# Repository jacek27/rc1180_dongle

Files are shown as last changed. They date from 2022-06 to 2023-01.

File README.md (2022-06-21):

# rc1180_dongle

Used the library files from SnapEDA https://www.snapeda.com/

PCB for RadioCraft's RC1180-MBUS3 module with CH340C for usage with https://github.com/weetmuts/wmbusmeters

Trace for antena was calculated using https://www.pcbway.com/pcb_prototype/impedance_calculator.html


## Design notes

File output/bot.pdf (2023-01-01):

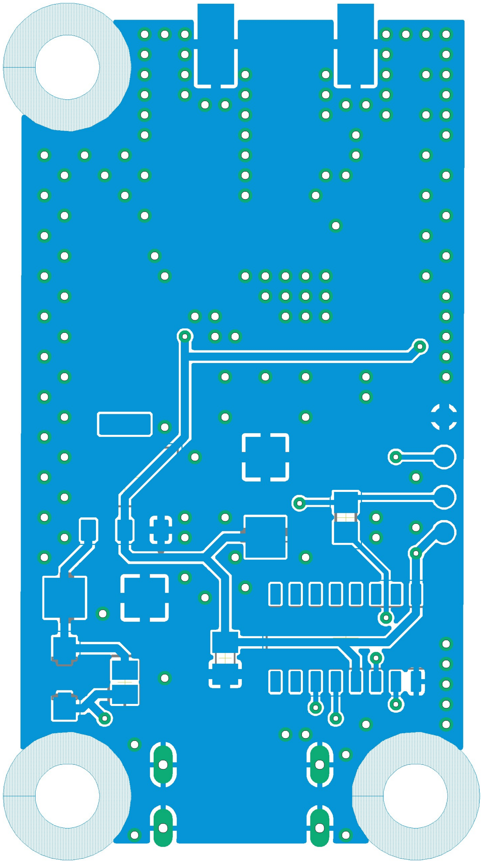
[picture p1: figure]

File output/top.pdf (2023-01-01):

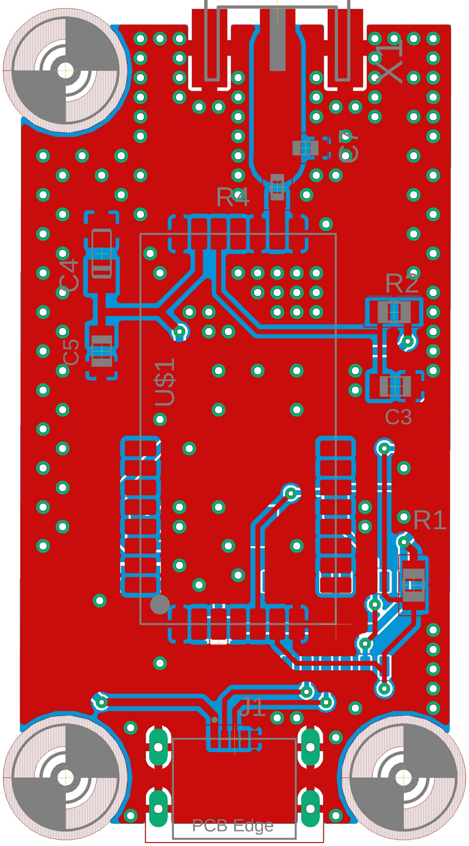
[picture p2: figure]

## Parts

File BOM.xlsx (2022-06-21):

Qty | Value | Device | Package | Parts | TME_PN | LINK | Description
3 | 100nF | C-EUC0805K | C0805K | C3, C5, C6 |  |  | CAPACITOR, European symbol
2 | 22uF | CPOL-EUC/6032-28R | C/6032-28R | C1, C2 | 293D226X9010C2TE3 | https://www.tme.eu/pl/details/293d226x9010c2te3/kondensatory-tantalowe-smd/vishay/ | POLARIZED CAPACITOR, European symbol
1 | 2u2F | CPOL-EUA/3216-18W | A/3216-18W | C4 | T491A225K020AT | https://www.tme.eu/pl/details/t491a225k020at/kondensatory-tantalowe-smd/kemet/ | POLARIZED CAPACITOR, European symbol
1 | 470R | R-EU_R0805 | R0805 | R3 |  |  | RESISTOR, European symbol
1 | 47642-0001 | 47642-0001 | MOLEX_47642-0001 | J1 | 476420001 | https://www.tme.eu/pl/details/mx-47642-0001/zlacza-usb-i-ieee1394/molex/476420001/ | Micro-USB B Receptacle, Mid-Mount, with Through Hole Solder Tab, Gold (Au) Flash Plating, without Mylar, Lead-Free
1 | 5k6 | R-EU_R0805 | R0805 | R2 |  |  | RESISTOR, European symbol
1 | 8k2 | R-EU_R0805 | R0805 | R1 |  |  | RESISTOR, European symbol
1 | AMS1117 | AMS1117 | SOT229P700X180-4N | U2 |  | https://elty.pl/pl/p/Stabilizator-napiecia-AMS1117-3%2C3V-SOT223-5-sztuk/972 | Sot223/Pkg 1-Amp 5-Volt Low Drop Out Voltage Regulatator
1 | CH340C | CH340C | SOIC127P600X180-16N | U1 |  | https://elty.pl/pl/p/Uklad-CH340C-SOP-16-konwerter-USB-TTL/2845 | USB to serial chip CH340
1 | MBR0540 | MBR0540 | SOD123 | U$2 | MBR0540-TP | https://www.tme.eu/pl/details/mbr0540-tp/diody-schottky-smd/micro-commercial-components/
1 | RC1180-MBUS3 | RC1180-MBUS3 | RC1180-MBUS3 | U$1 | RC1180-MBUS3 | https://www.tme.eu/pl/details/rc1180-mbus3/moduly-rf/radiocrafts/
1 | SMA-142-0701-801/806 | SMA-142-0701-801/806 | J502-ND-142-0701-801/806 | X1 | KAB-06318 | https://allegro.pl/oferta/zlacze-zenskie-sma-do-druku-proste-50ohm-12145586412 | SMA 50 Ohm End Launch Jack Receptacle - Round Contact
1 | TBD | C-EUC0603 | C0603 | C7 |  |  | CAPACITOR, European symbol
1 | TBD | R-EU_R0603 | R0603 | R4 |  |  | RESISTOR, European symbol

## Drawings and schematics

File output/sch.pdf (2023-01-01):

A

A

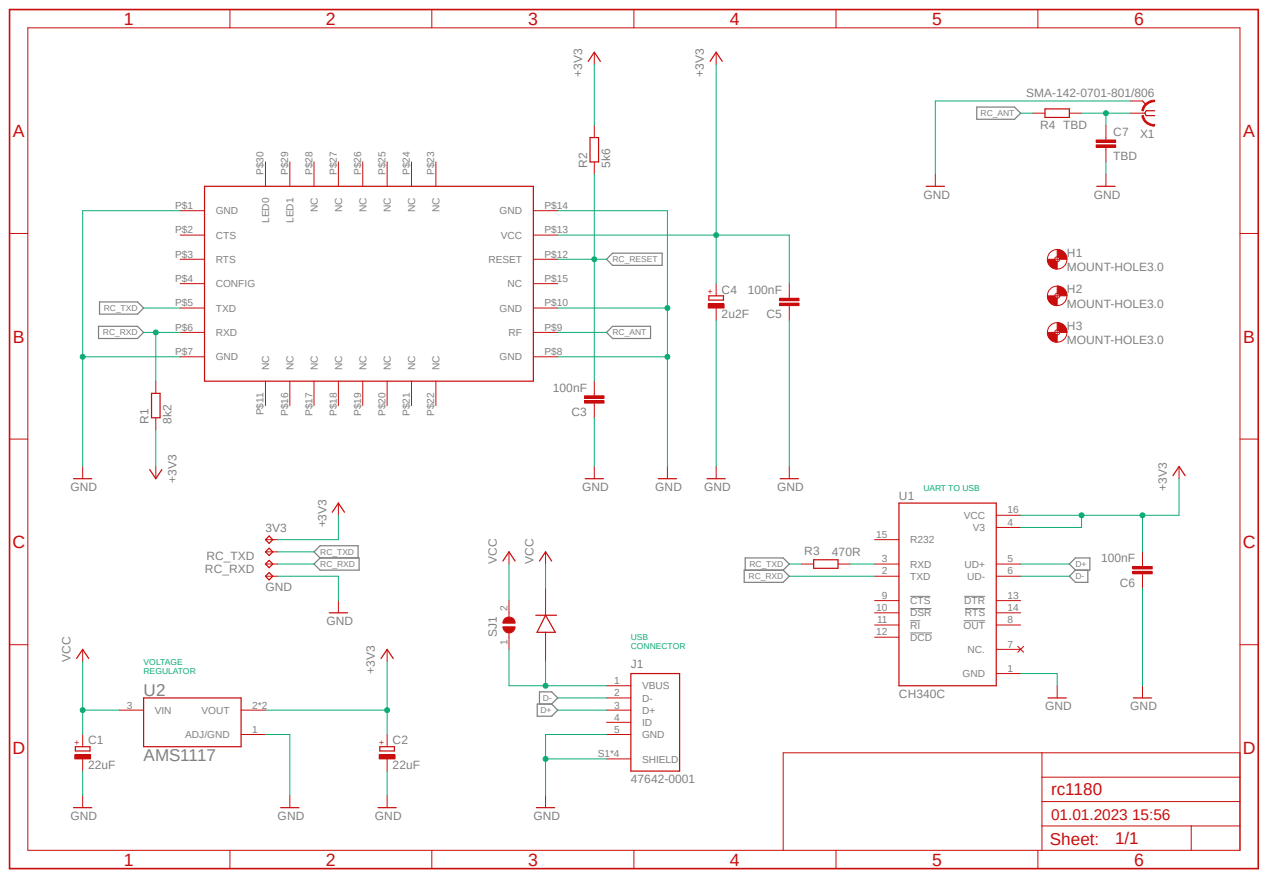
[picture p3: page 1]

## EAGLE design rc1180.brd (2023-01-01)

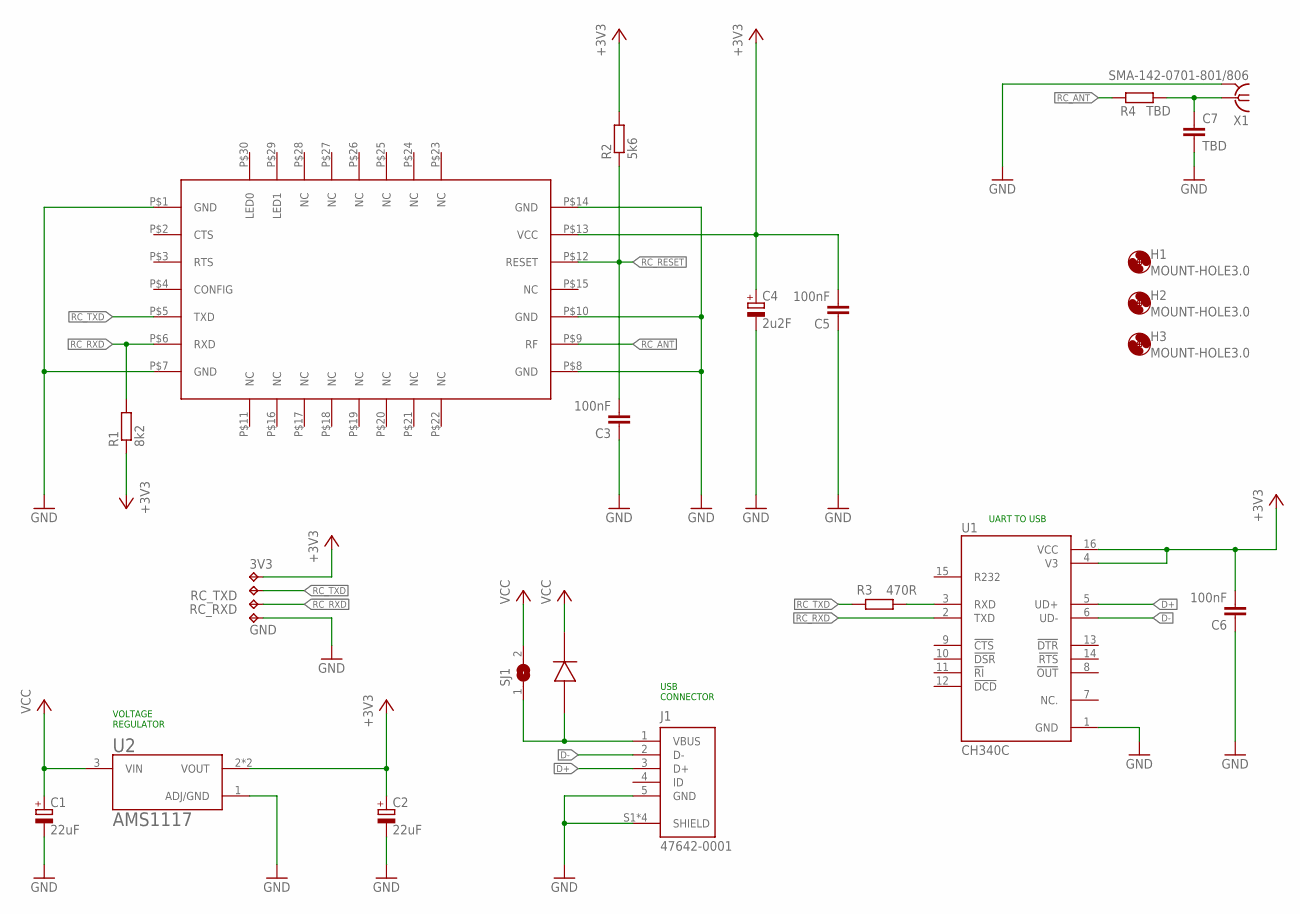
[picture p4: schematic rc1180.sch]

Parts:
3V3: TPB1,27; B1,27
C1, C2: 22uF; C/6032-28R
C3, C5, C6: 100nF; C0805K
C4: 2u2F; A/3216-18W
C7: TBD; C0603
GND: TPB1,27; B1,27
H1, H2, H3: MOUNT-HOLE3.0; 3,0
J1: 47642-0001; MOLEX_47642-0001
R1: 8k2; R0805
R2: 5k6; R0805
R3: 470R; R0805
R4: TBD; R0603
RC_RXD: TPB1,27; B1,27
RC_TXD: TPB1,27; B1,27
SJ1: SJ
U1: CH340C; SOIC127P600X180-16N
U2: AMS1117; SOT229P700X180-4N
U$1: RC1180-MBUS3
U$2: MBR0540; SOD123
X1: SMA-142-0701-801/806; J502-ND-142-0701-801/806

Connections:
+3V3: 3V3.TP, C2.+, C4.+, C5.2, C6.2, R1.1, R2.2, U1.4 (V3), U1.16 (VCC), U2.2 (VOUT), U2.4 (VOUT), U$1.P$13 (VCC)
D+: J1.3 (D+), U1.5 (UD+)
D-: J1.2 (D-), U1.6 (UD-)
GND: C1.-, C2.-, C3.1, C4.-, C5.1, C6.1, C7.2, GND.TP, J1.5 (GND), J1.S1 (SHIELD), J1.S2 (SHIELD), J1.S3 (SHIELD), J1.S4 (SHIELD), U1.1 (GND), U2.1 (ADJ/GND), U$1.P$1 (GND), U$1.P$7 (GND), U$1.P$8 (GND), U$1.P$10 (GND), U$1.P$14 (GND), X1.G@1 (2), X1.G@2 (2), X1.G@3 (2), X1.G@4 (2)
unnamed: R3.2, U1.3 (RXD)
unnamed: J1.1 (VBUS), SJ1.1, U$2.A
unnamed: C7.1, R4.2, X1.1
RC_ANT: R4.1, U$1.P$9 (RF)
RC_RESET: C3.2, R2.1, U$1.P$12 (RESET)
RC_RXD: R1.2, RC_RXD.TP, U1.2 (TXD), U$1.P$6 (RXD)
RC_TXD: R3.1, RC_TXD.TP, U$1.P$5 (TXD)
VCC: C1.+, SJ1.2, U2.3 (VIN), U$2.C (K)

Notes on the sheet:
USB CONNECTOR
VOLTAGE REGULATOR
UART TO USB

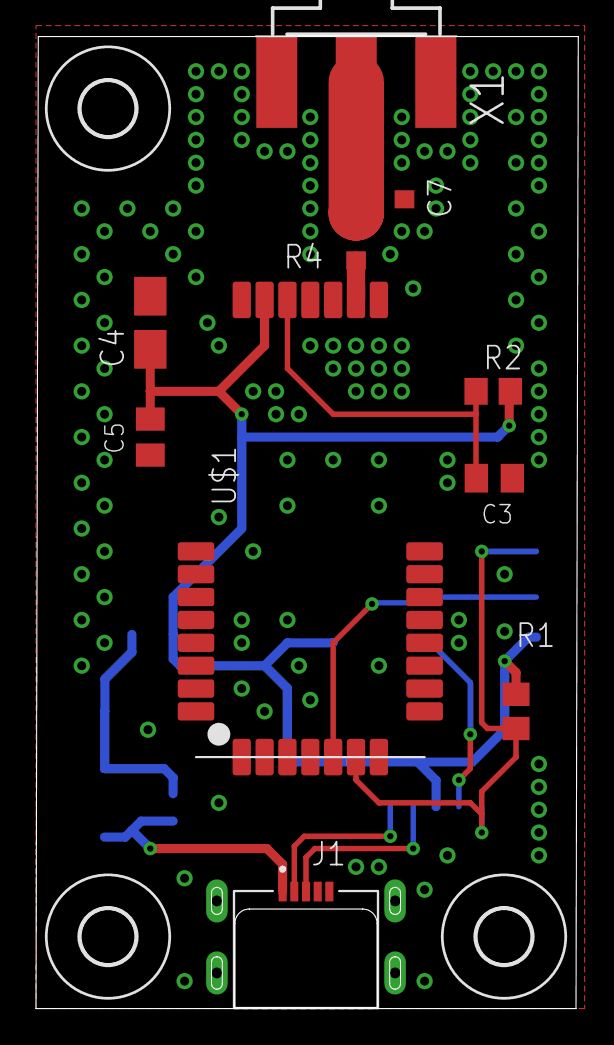
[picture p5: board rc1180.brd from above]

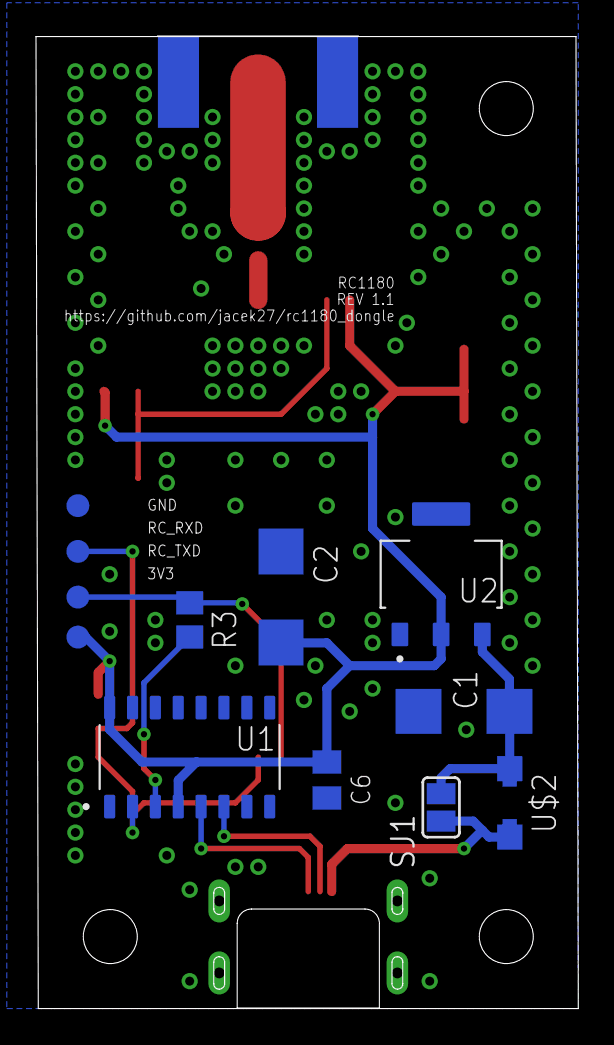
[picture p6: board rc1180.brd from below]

Board: 2 copper layers, 30.1 x 54.0 mm, 25 parts (12 on the bottom side), 12 nets.

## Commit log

2022-06-15 Added schematics and epf files
    [rc1180.sch]
2022-06-17 Added ch340 and ams1117 vreg
    [rc1180.sch]
2022-06-18 Component placed / frame added
    [rc1180.sch]
2022-06-18 Final touches
    [rc1180.sch]
2022-06-18 First board commit
    [rc1180.brd]
2022-06-18 Added holes and vias
    [rc1180.brd, rc1180.sch]
2022-06-18 Added more vias and corrected component desc
    [rc1180.brd]
2022-06-19 Added matching circuit for antenna
    [rc1180.sch]
2022-06-21 Updated 100nF caps to be the same
    [rc1180.sch]
2022-06-21 BOM based on Polish sources
    [BOM.xlsx]
2022-06-21 Extended board to 54 mm for easy soldering of rf connector
    [rc1180.brd]
2022-06-21 Connected the 100nF updated cap
    [rc1180.brd]
2023-01-01 Added vias and testpoints
    [rc1180.brd, rc1180.sch]
2023-01-01 Updated layer sets
    [rc1180.brd]
2023-01-01 Added pdf prints
